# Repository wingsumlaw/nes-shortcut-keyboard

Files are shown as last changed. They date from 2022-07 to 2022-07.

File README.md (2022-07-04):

# Shortcut keyboard in an NES-style casing

While I put all this hardware into an NES-inspired case, this will work in any case with the screen, rotary encoder, and 10 keys.

## Setup

Use the programs.py document to customize the shortcut keyboard. For each program you'd like to have a custom set of shortcuts for, add an OrderedDict to the dicts list. Use the [Adafruit keycode library](https://docs.circuitpython.org/projects/hid/en/latest/_modules/adafruit_hid/keycode.html) to determine which codes to use.

```py
dicts = [
    OrderedDict(
        d_pad_left=[Keycode.COMMAND, Keycode.D],                # deselect
        d_pad_down=[Keycode.ALT, Keycode.LEFT_BRACKET],         # down layer
        bottom_left=[Keycode.COMMAND, Keycode.S],               # save
        bottom_right=[Keycode.COMMAND, Keycode.V],              # paste
        start=[Keycode.COMMAND, Keycode.Y],                     # redo
        d_pad_up=[Keycode.ALT, Keycode.RIGHT_BRACKET],          # up layer                  
        d_pad_right=[Keycode.COMMAND, Keycode.T],               # transform
        top_left=[Keycode.COMMAND, Keycode.C],                  # copy
        top_right=[Keycode.COMMAND, Keycode.X],                 # cut
        select=[Keycode.COMMAND, Keycode.Z],                    # undo
        encoder0_up=[Keycode.COMMAND, Keycode.KEYPAD_PLUS],     # zoom in
        encoder0_down=[Keycode.COMMAND, Keycode.KEYPAD_MINUS],  # zoom out
        encoder1_up=[Keycode.EQUALS],                           # rotate canvas right
        encoder1_down=[Keycode.MINUS],                          # rotate canvas left
        name="ClipStudio",                                      # program name
        light_color=(255,255,255)                               # light color
    )
]
```

While this software could potentially manage a great number of programs, keep in mind that the OLED screen in its current state will only show 4 programs.

## Links

See more info on the construction and design of the NES Shortcut Keyboard can be found at...

* [My Website](https://www.wingsumlaw.com)
* [Hackaday Post](https://hackaday.io/project/186123-nes-shortcut-keyboard)

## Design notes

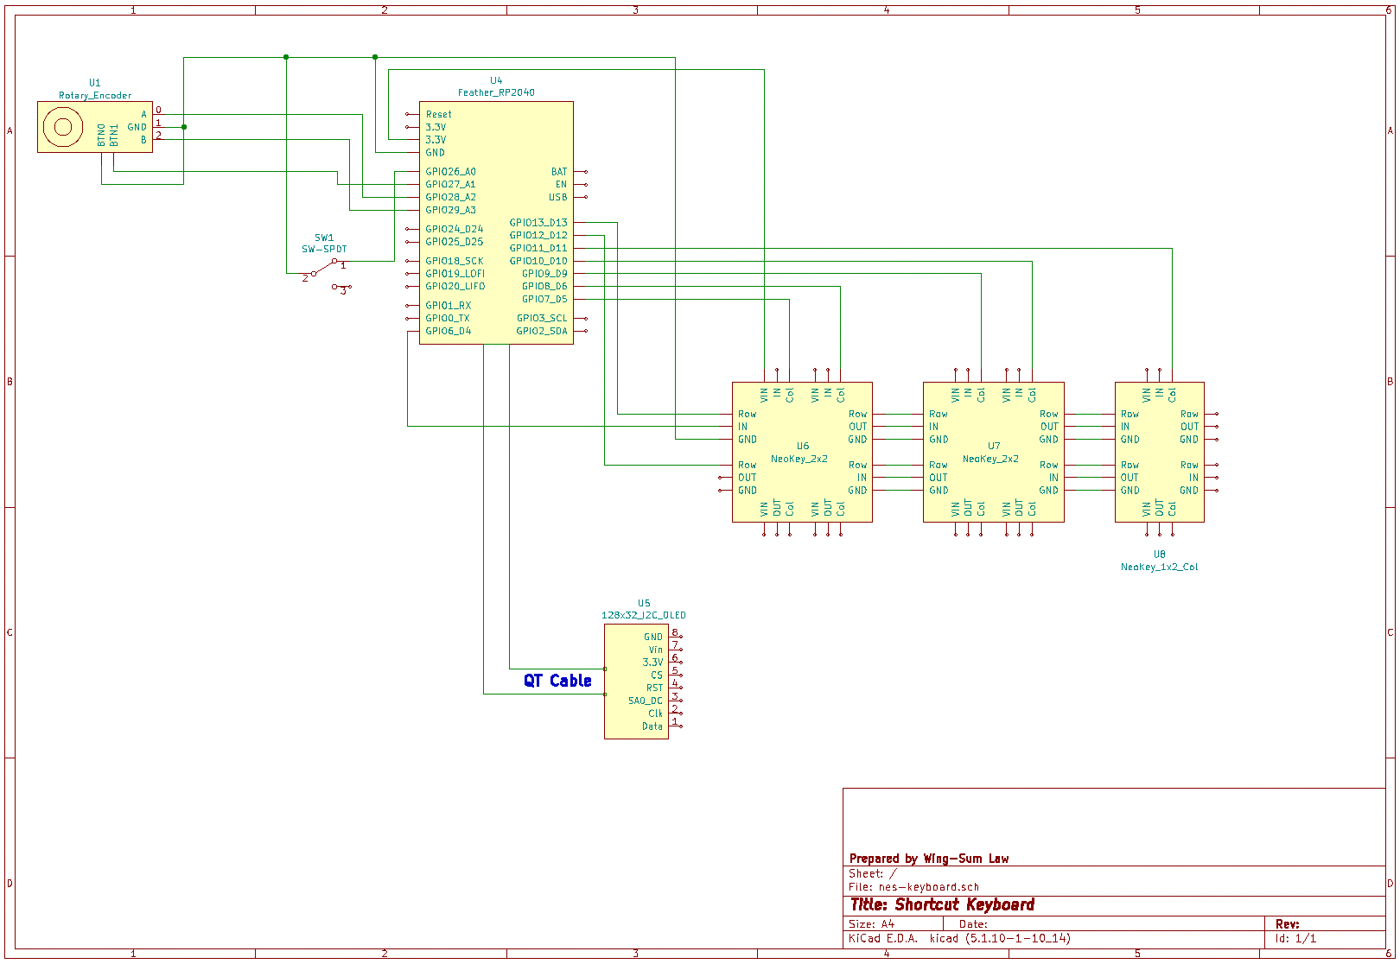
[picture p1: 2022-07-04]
circuit_schematic.png

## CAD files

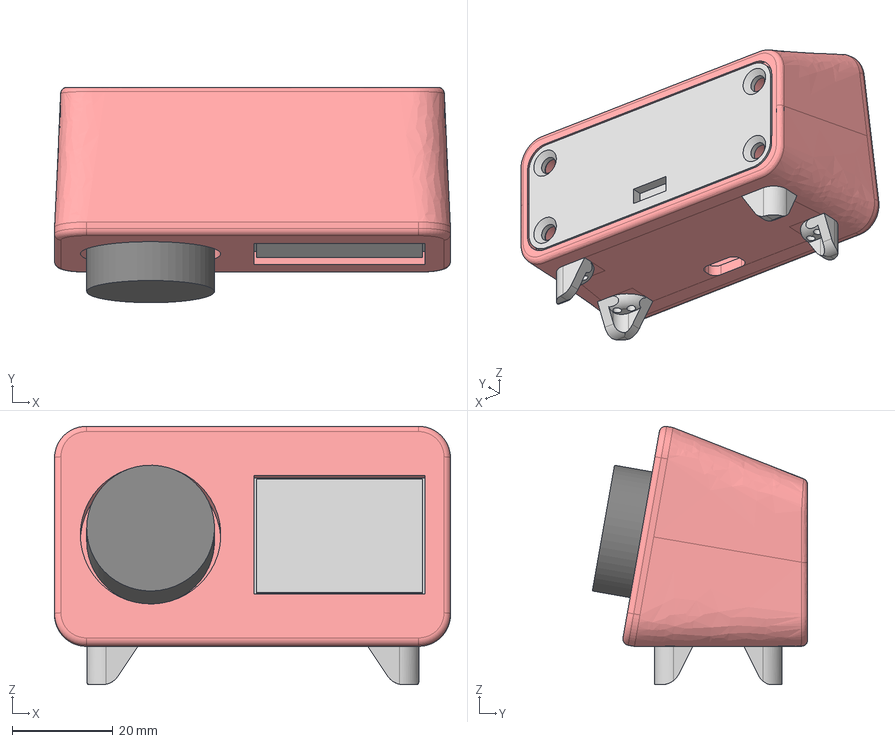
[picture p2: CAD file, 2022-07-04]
cad/TV v11.step
78.7 x 42.8 x 51.4 mm
OLED Screen
Case
Encoder Knobs
Legs

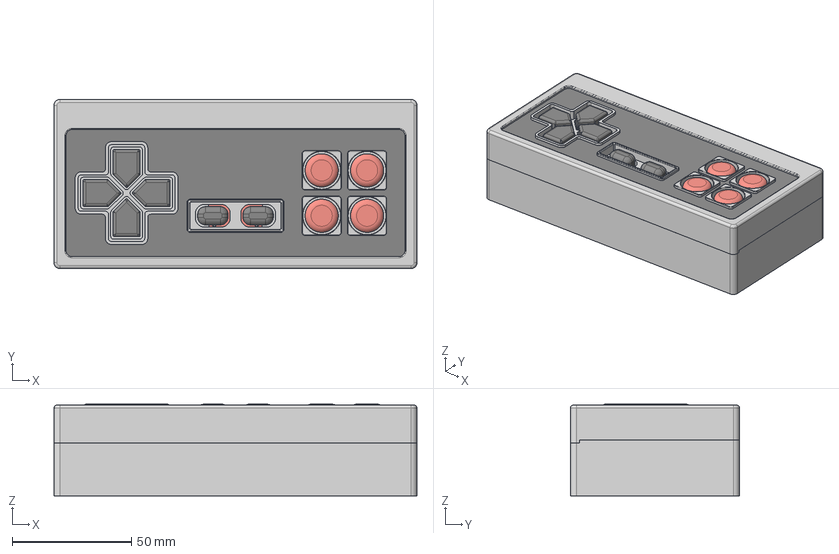
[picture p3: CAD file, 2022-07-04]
cad/NES-Shortcut-Keyboard v45.step
152.4 x 71.1 x 38.5 mm
Feather PCB
D-Pad
Select Start
ABXY
Standoffs
Bottom Case

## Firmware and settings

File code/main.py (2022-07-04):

'''
NES Shortcut Keyboard
main.py
Wing-Sum Law

Resources:
- Please see Adafruit's various guides to CircuitPython (https://learn.adafruit.com/intro-to-rp2040-pio-with-circuitpython/overview)
- Check the libraries (https://github.com/adafruit/Adafruit_CircuitPython_Bundle/releases)

Usage:
- Update programs & associated shortucts in the programs.py file
'''

''' ******** IMPORTS ******** '''

# Imports from Adafruit
import board
import keypad
import neopixel
import rotaryio
import digitalio
import displayio
import adafruit_displayio_ssd1306

# Imports of own modules
import programs
import keypad_helper
import encoder_helper
import oled_helper
import state_classes

# Program names
program_names = [p["name"] for p in programs.dicts]

''' ******** BOARD IO ******** '''

# LEDs under keys, IN goes to D4 on Feather, start LEDs in default color
lights = neopixel.NeoPixel(board.D4, 10, brightness = 0.1)
lights.fill(programs.dicts[0]["light_color"])

# The keypad
keys = keypad.KeyMatrix(
    row_pins = (board.D12, board.D13),
    column_pins = (board.D5, board.D6, board.D9, board.D10, board.D11),
    columns_to_anodes=False
)

# The buttons on the rotary knobs
encoder_btn = keypad.Keys((board.A1,), value_when_pressed=False, pull=True)

# The rotary knobs
encoder = rotaryio.IncrementalEncoder(board.A2, board.A3)

last_encoder_pos = None

# The slide switch
switch = digitalio.DigitalInOut(board.A0)
switch.direction = digitalio.Direction.INPUT
switch.pull = digitalio.Pull.UP

''' ******** OLED SCREEN ******** '''

# I2C for OLED
displayio.release_displays()
i2c = board.I2C()
display_bus = displayio.I2CDisplay(i2c, device_address=0x3d)

WIDTH = 128
HEIGHT = 64
BORDER = 5

display = adafruit_displayio_ssd1306.SSD1306(display_bus, width=WIDTH, height=HEIGHT)

# Initial program display
display.show(oled_helper.display_current_program(program_names[0]))


''' ******** STATES ******** '''

# State describes whether currently in a program running shortcuts or choosing a program
STATE = state_classes.States()
ENCODER_MODE = state_classes.EncoderMode()
current_state = STATE.RUNNING_SHORTCUTS
current_encoder_mode = ENCODER_MODE.MODE_1

# Default to first program in list of programs
current_program = 0


''' ******** STATE FUNCTIONS ******** '''

def run_shortcuts(current_state, current_program, current_encoder_mode):
    '''
    A program is active and shortcuts are running
    Check for button and key events
    First resolve encoder button presses -- if encoder 0 is pressed the return state will be different
    Then check for keypad events and execute any associated shortcuts
    Then check for encoder movement and execute any associated shortcuts
    '''

    # Assume no state change
    return_state = current_state
    return_program = current_program
    return_encoder_mode = current_encoder_mode

    # Use global var for last encoder position
    global last_encoder_pos

    # Check for keypad, encoder, and switch for events
    key_event = keys.events.get()
    btn_event = encoder_btn.events.get()

    # Check if selecting or running
    if switch.value:
        return_state = STATE.CHOOSING_PROGRAM
    else:
        return_state = STATE.RUNNING_SHORTCUTS
        
    # Switch encoder mode if button is pressed
    if btn_event:
        if btn_event.pressed:
            return_encoder_mode = abs(current_encoder_mode - 1)
    
    # Check if keypad has been pressed
    if key_event:
        keypad_helper.press_keys(key_event, current_program)

    # Check if  encoder has moved
    position = encoder.position
    encoder_helper.run_encoder_changes(current_encoder_mode, position, last_encoder_pos, current_program)
    last_encoder_pos = position

    return return_state, return_program, return_encoder_mode


def choose_program(current_state, current_program, current_encoder_mode):
    '''
    No program is active and one must be chosen
    Check to see if encoder 0 has moved and determine which program corresponds to that movement
    Then check to see if encoder 0 has been pressed, indicating return to running shortcuts
    '''

    # Assume no state change
    return_state = current_state
    return_program = current_program
    return_encoder_mode = current_encoder_mode

    # Use global var for last encoder position
    global last_encoder_pos

    # Display program selection screen
    display.show(oled_helper.display_choose_program(return_program, program_names))

    # If encoder has moved, change to correct program
    position = encoder.position
    return_program = encoder_helper.change_program(position, last_encoder_pos, current_program)
    last_encoder_pos = position
    
    # Switch lights
    lights.fill(programs.dicts[return_program]["light_color"])

    # Check to see if program is locked in
    if not switch.value:
        return_state = STATE.RUNNING_SHORTCUTS
        display.show(oled_helper.display_current_program(program_names[return_program]))

    return return_state, return_program, return_encoder_mode


STATE_FUNCTIONS = {
    0: run_shortcuts,
    1: choose_program
}


# MAIN LOOP
while True:
    # Run appropriate state function
    current_state, current_program, current_encoder_mode = STATE_FUNCTIONS[current_state](current_state, current_program, current_encoder_mode)

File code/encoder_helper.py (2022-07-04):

'''
NES Shortcut Keyboard
encoder_helper.py
Wing-Sum Law

Helper for checking encoder buttons and movement
Executes any corresponding shortcuts using keypad_helper
'''

import state_classes
import programs
import keypad_helper

STATE = state_classes.States()
ENCODER_MODE = state_classes.EncoderMode()


def run_encoder_changes(encoder_mode, position, last_position, current_program):
    '''
    A program is active and shortcuts are running
    Determine position change and execute corresponding shortcut
    '''

    # Determine position change
    position_change = check_encoder_rotation(position, last_position)

    # Determine which encoder commands to use
    if encoder_mode == ENCODER_MODE.MODE_1:
        adj = 0
    else:
        adj = 2

    # Determine what function position change corresponds to
    if position_change < 0:
        key_sequence = list(programs.dicts[current_program].items())[10 + adj]
        keypad_helper.execute_shortcut(key_sequence)
    elif position_change > 0:
        key_sequence = list(programs.dicts[current_program].items())[11 + adj]
        keypad_helper.execute_shortcut(key_sequence)


def change_program(position, last_position, current_program):
    '''
    No program is active and one must be chosen
    Determine position change and map to new program
    '''
    # Assume no change
    return_program = current_program

    # Determine position change
    position_change = check_encoder_rotation(position, last_position)

    # Determine which program position_change corresponds to
    return_program = (current_program + position_change) % programs.num

    return return_program


def check_encoder_rotation(position, last_position):
    '''
    Using last position and current position, determine how much position of encoder has changed
    '''

    # Default to no position change
    position_change = 0

    # Determine if position has a non-zero change
    if last_position is None:
        position_change = position - 0
    elif last_position != position:
        position_change = position - last_position

    return position_change

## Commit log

2022-07-04 updated software to include oled screen control. updated software to reflect change to single encoder.
    [nes-keyboard.kicad_pcb, nes-keyboard.sch]
2022-07-04 added electrical schematic and cad files
    [NES-Shortcut-Keyboard v45.step, TV v11.step, nes-keyboard.sch]
2022-07-04 updated circuit schematic png
